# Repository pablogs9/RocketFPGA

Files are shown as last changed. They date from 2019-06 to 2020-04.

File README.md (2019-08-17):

# RocketFPGA :sound::rocket:
Why buy a iCE40UP5k breakout when it is possible to make one?
<p align="center">
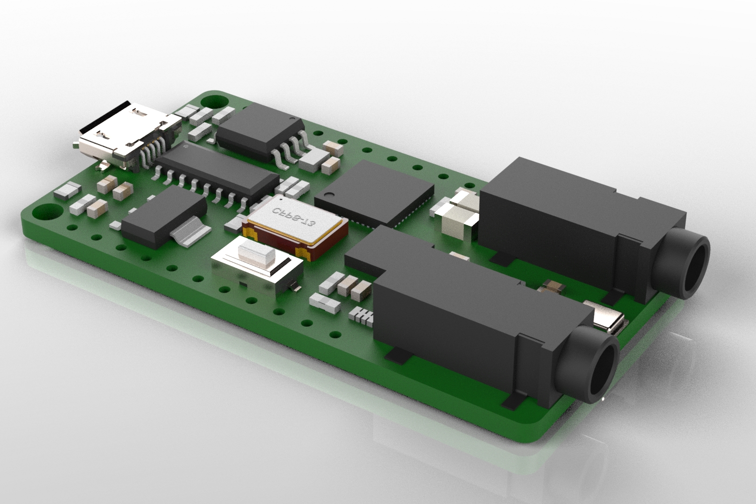
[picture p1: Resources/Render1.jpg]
  
</p>

## What is  this?
This aims to be another FPGA breakout board. What makes this board special is the
usage of a cheap CH551 microcontroller as the bridge between the USB and 
flash memory. This microcontroller could also be used to interface the FPGA and 
the USB, opening a lot of new possibilities.

The current hardware development is focushed on adding an audio codec and a couple
of audio jack to set the focus this board in sound synthesis with 
FPGAs :smiling_imp:.

<p align="center">
  
</p>

## Repo structure:
- Hardware: Contains the Altium PCB design files. (At some point we will clone this on kicad)
- Software
  -  CH551 Bootloader: Contains the source files of the CH551 flash writer.
  -  Code uploader: Contains a python script that uploads the synthesized FPGA code to the board.
  -  FPGA Sample code: Contains a bunch of verilog examples.

## TODO:
- [ ] Improve heavily the documentation (instructions, wiki etc)
- [ ] Finish the board with the audio codec
- [ ] Create audio related verilog code (once the board is finished)
- [ ] Rethink the TODOs

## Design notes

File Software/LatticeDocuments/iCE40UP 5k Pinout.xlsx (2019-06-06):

# Pin Out For iCE5UP5K (iCE40 UltraPlus - 5K)
# Revision 0.4 - Remove FWG49
# Revision 1.1 - Fix RGB pins, swapped C5 & A5 pins as well as 39 & 41
# Updated Jun 19, 2017
FNC | Pin Type | BANK | Differential Pair | UWG30 | SG48
IOB_0a | PIO | 2 |  | E5 | 46
IOB_2a | DPIO | 2 | TRUE_of_IOB_3b | D5 | 47
IOB_3b_G6 | DPIO/GBIN | 2 | COMP_of_IOB_2a | F5 | 44
IOB_4a | DPIO | 2 | TRUE_of_IOB_5b | - | 48
IOB_5b | DPIO | 2 | COMP_of_IOB_4a | - | 45
IOB_6a | PIO | 2 |  | - | 2
IOB_8a | DPIO | 2 | TRUE_of_IOB_9b | - | 4
IOB_9b | DPIO | 2 | COMP_of_IOB_8a | E4 | 3
IOB_10a | DPIO | 1 | TRUE_of_IOB_11b | C3 | -
IOB_11b_G5 | DPIO/GBIN | 1 | COMP_of_IOB_10a | F4 | -
creset_b | CONFIG | 1 |  | F3 | 8
IOB_12a_G4_CDONE | CONFIG/DPIO/GBIN | 1 | TRUE_of_IOB_13b | D3 | -
CDONE | CONFIG | 1 |  | - | 7
IOB_13b | DPIO | 1 | COMP_of_IOB_12a | E3 | 6
IOB_16a | PIO | 1 |  | - | 9
IOB_18a | PIO | 1 |  | - | 10
IOB_20a | PIO | 1 |  | - | 11
IOB_22a | DPIO | 1 | TRUE_of_IOB_23b | - | 12
IOB_23b | DPIO | 1 | COMP_of_IOB_22a | - | 21
IOB_24a | DPIO | 1 | TRUE_of_IOB_25b | B1 | 13
IOB_25b_G3 | DPIO/GBIN | 1 | COMP_of_IOB_24a | F2 | 20
IOB_29b | PIO | 1 |  | - | 19
IOB_31b | PIO | 1 |  | - | 18
IOB_32a_SPI_SO | DPIO/CONFIG_SPI | 1 |  | F1 | 14
IOB_33b_SPI_SI | DPIO/CONFIG_SPI | 1 |  | E1 | 17
IOB_34a_SPI_SCK | DPIO/CONFIG_SPI | 1 |  | D1 | 15
IOB_35b_SPI_SS | DPIO/CONFIG_SPI | 1 |  | C1 | 16
VCCPLL | VCCPLL |  |  | B2 | 29
IOT_36b | DPIO/I3C | 0 | COMP_of_IOT_37a | A1 | 25
IOT_37a | DPIO/I3C | 0 | TRUE_of_IOT_36b | A2 | 23
IOT_38b | DPIO | 0 | COMP_of_IOT_39a | - | 27
IOT_39a | DPIO | 0 | TRUE_of_IOT_38b | - | 26
IOT_41a | PIO | 0 |  | - | 28
IOT_42b | DPIO | 0 | COMP_of_IOT_43a | - | 31
IOT_43a | DPIO | 0 | TRUE_of_IOT_42b | - | 32
IOT_44b | DPIO | 0 | COMP_of_IOT_45a | - | 34
IOT_45a_G1 | DPIO/GBIN | 0 | TRUE_of_IOT_44b | - | 37
IOT_46b_G0 | DPIO/GBIN | 0 |  | B3 | 35
IOT_47a | PIO | 0 |  | A4 | -
IOT_48b | DPIO | 0 | COMP_of_IOT_49a | - | 36
IOT_49a | DPIO | 0 | TRUE_of_IOT_48b | - | 43
IOT_50b | DPIO | 0 | COMP_of_IOT_51a | - | 38
IOT_51a | DPIO | 0 | TRUE_of_IOT_50b | - | 42
RGB2 | LED | 0 |  | C5 | 41
RGB1 | LED | 0 |  | B5 | 40
RGB0 | LED | 0 |  | A5 | 39
GND | GND | GND |  | B4 | Paddle
GND | GND | GND |  | E2 | Paddle
GND | GND | GND |  | - | Paddle
VCC | VCC | VCC |  | C2 | 5
VCC | VCC | VCC |  | - | 30
VCCIO_0 | VCCIO | 0 |  | A3 | 33
SPI_Vccio1 | VCCIO | 1 |  | D2 | 22
VCCIO_2 | VCCIO | 2 |  | C4 | 1
VPP_2V5 | VPP | VPP |  | D4 | 24
*SG48 GND is connected to package paddle

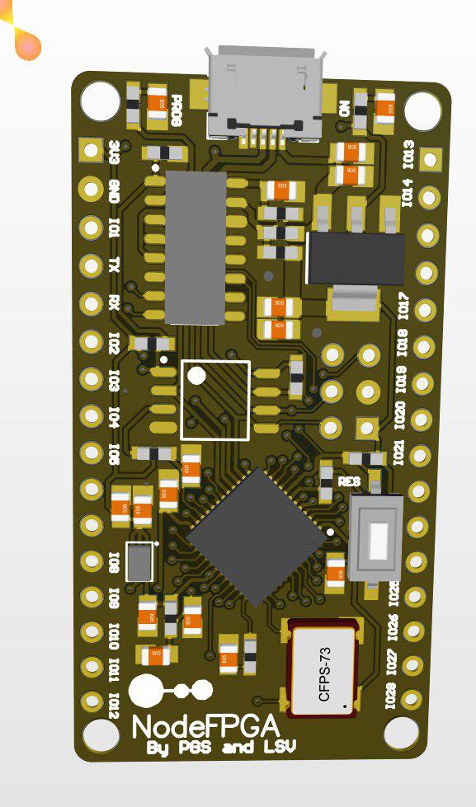
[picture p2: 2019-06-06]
Resources/NodeFPGA_cad.jpg

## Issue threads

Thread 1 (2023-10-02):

Where do I buy one?

PythonLinks, 2023-10-02:
I believe that there are no shipping ICE40 boards with audio ports.   There are some with pmod ports, but then one has to buy more stuff to plug in.  It is an important market which is not being served.

There are several of us interested in Audio.
We are looking at the Pico-Ice
 https://pico-ice.tinyvision.ai/

And the Pico Fabric.
https://picolemon.com/board/picofabric

The problem with the Pico Ice is that we have to separately buy the Diligent pmod, and worse yet solder pmods onto the boards.  Sure I can do that, but my users will have a hard time doing it.  The holes are so small, even I will have a hard time doing it.

The problem with the Pico Fabric is that it does not quite work yet, and they are waiting for parts for 3 more months.  Also it uses the ECP5, and is more expensive.  And it does not have audio input.

You are most welcome to join our discord servers and meet us.

Pico Ice Discord Server:  https://discord.gg/MY6cAgs5

Pico Fabric Discord Server: https://discord.gg/8Kdr2TtY

The great thing about joining this group, is that we will then build the Audio Verilog for you.  In fact I am already building it.  The Upduino has one pmod  presoldered where I can plug in the Diligent stereoaudio pmod. Or at least the audio out part of that Diligent audio pmod.   At least two of us have that UPduino board.

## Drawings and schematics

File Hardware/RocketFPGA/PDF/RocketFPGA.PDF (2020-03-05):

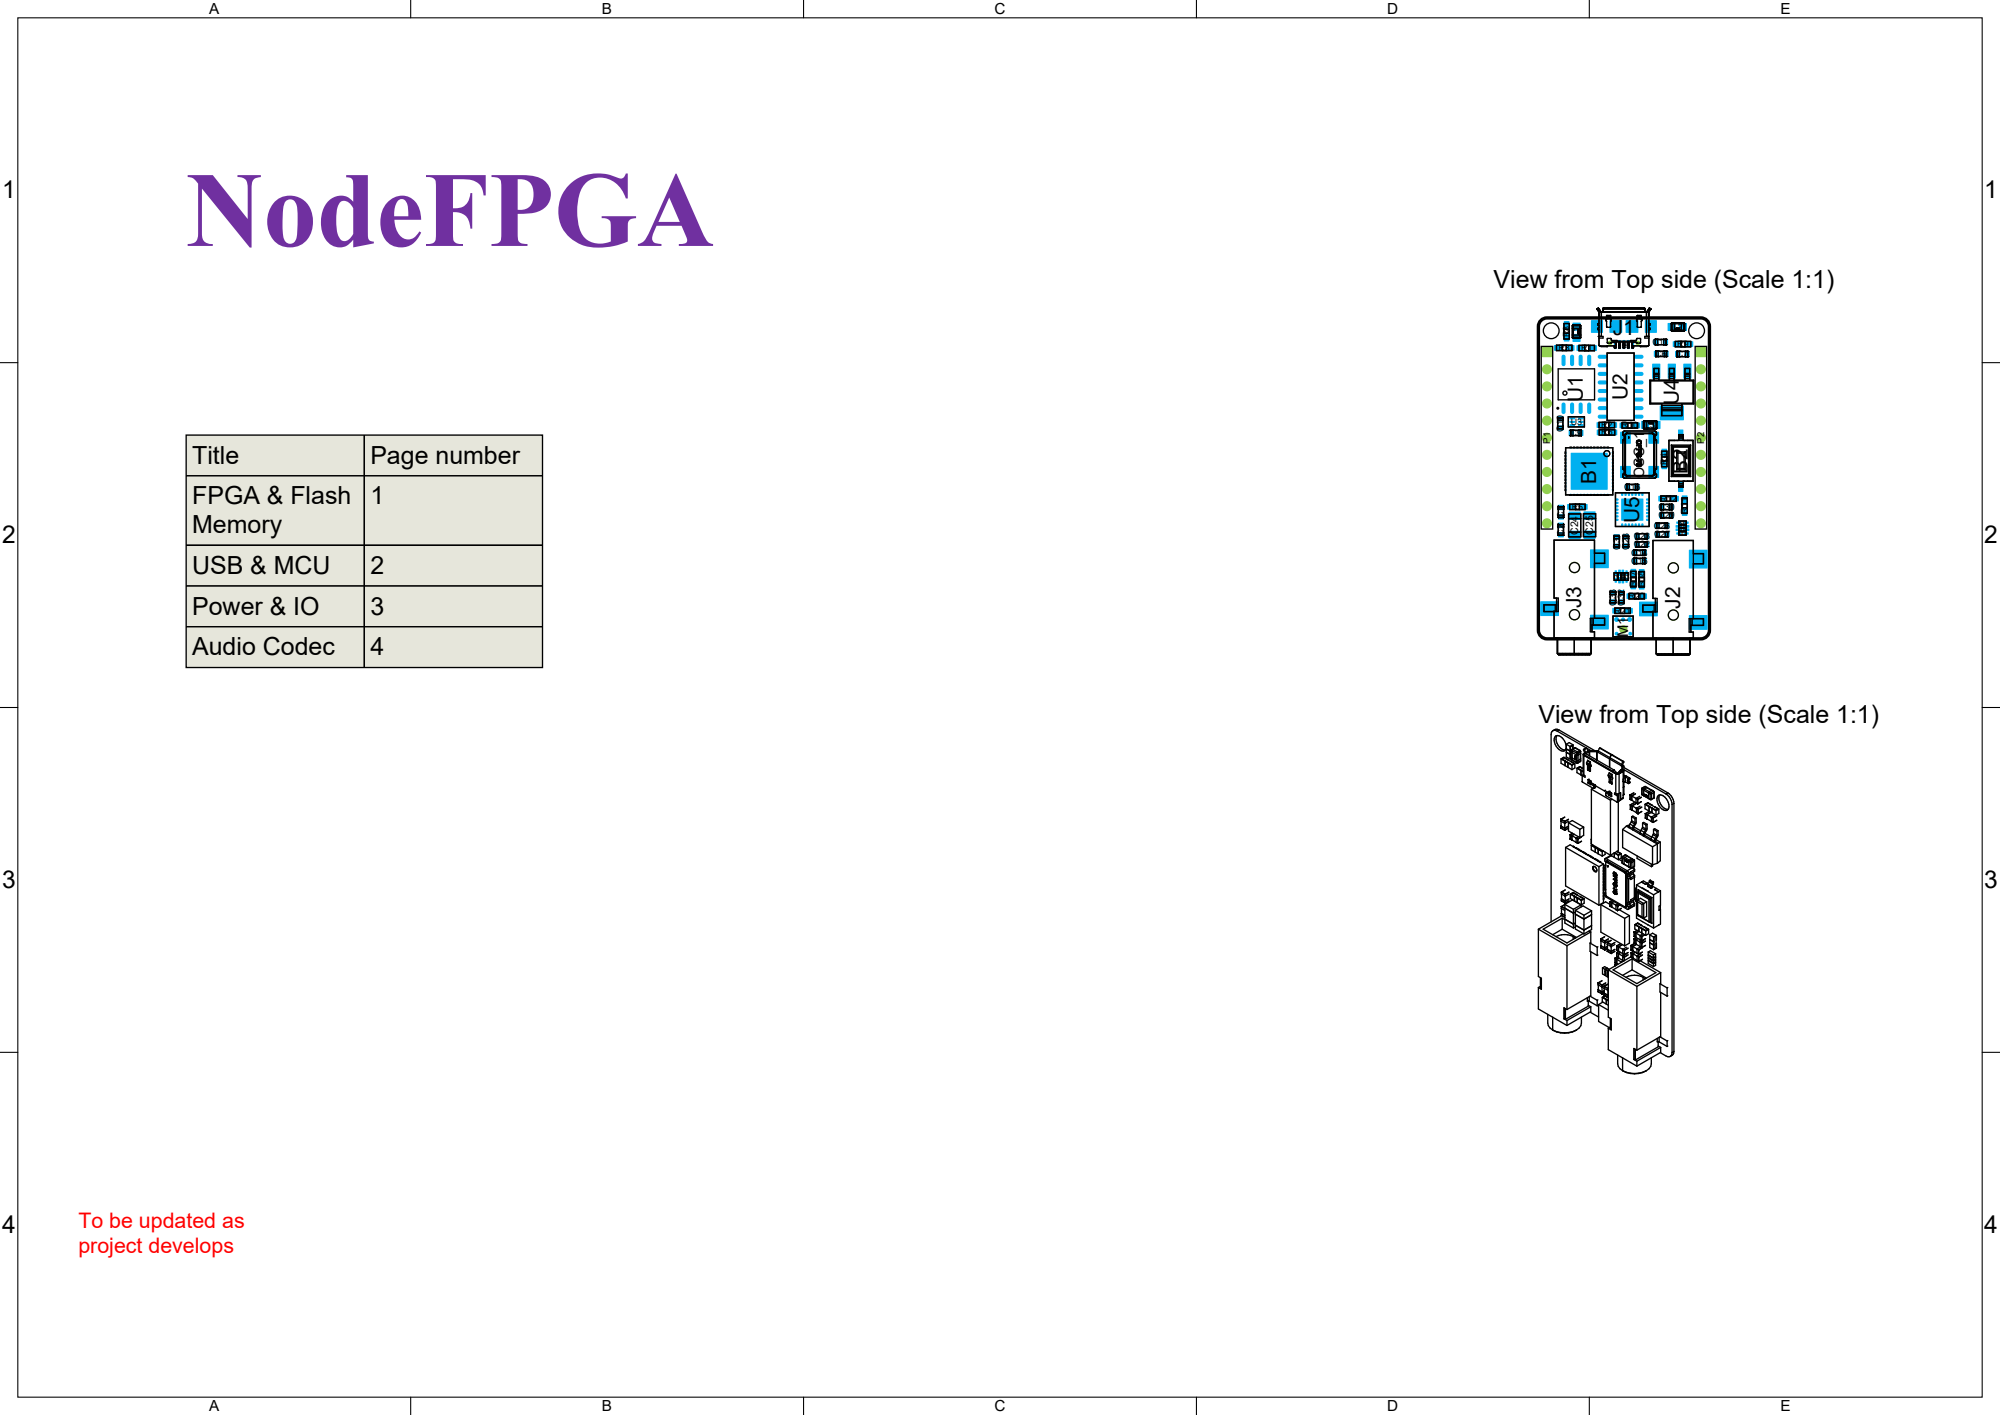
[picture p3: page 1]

View from Top side (Scale 1:1)

To be updated as

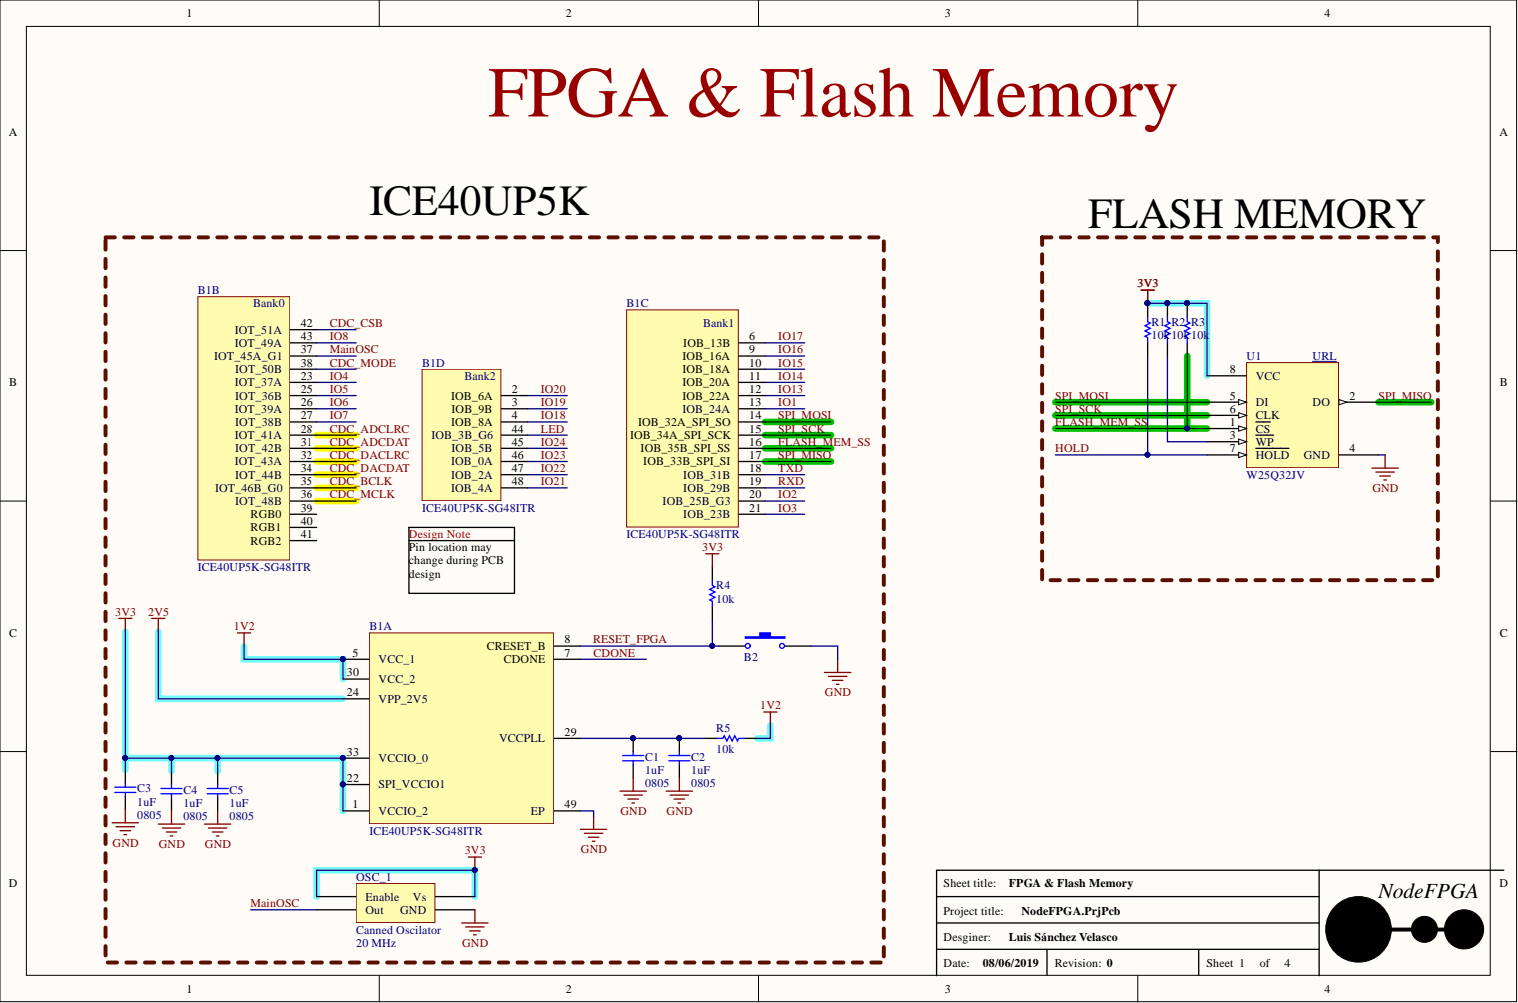
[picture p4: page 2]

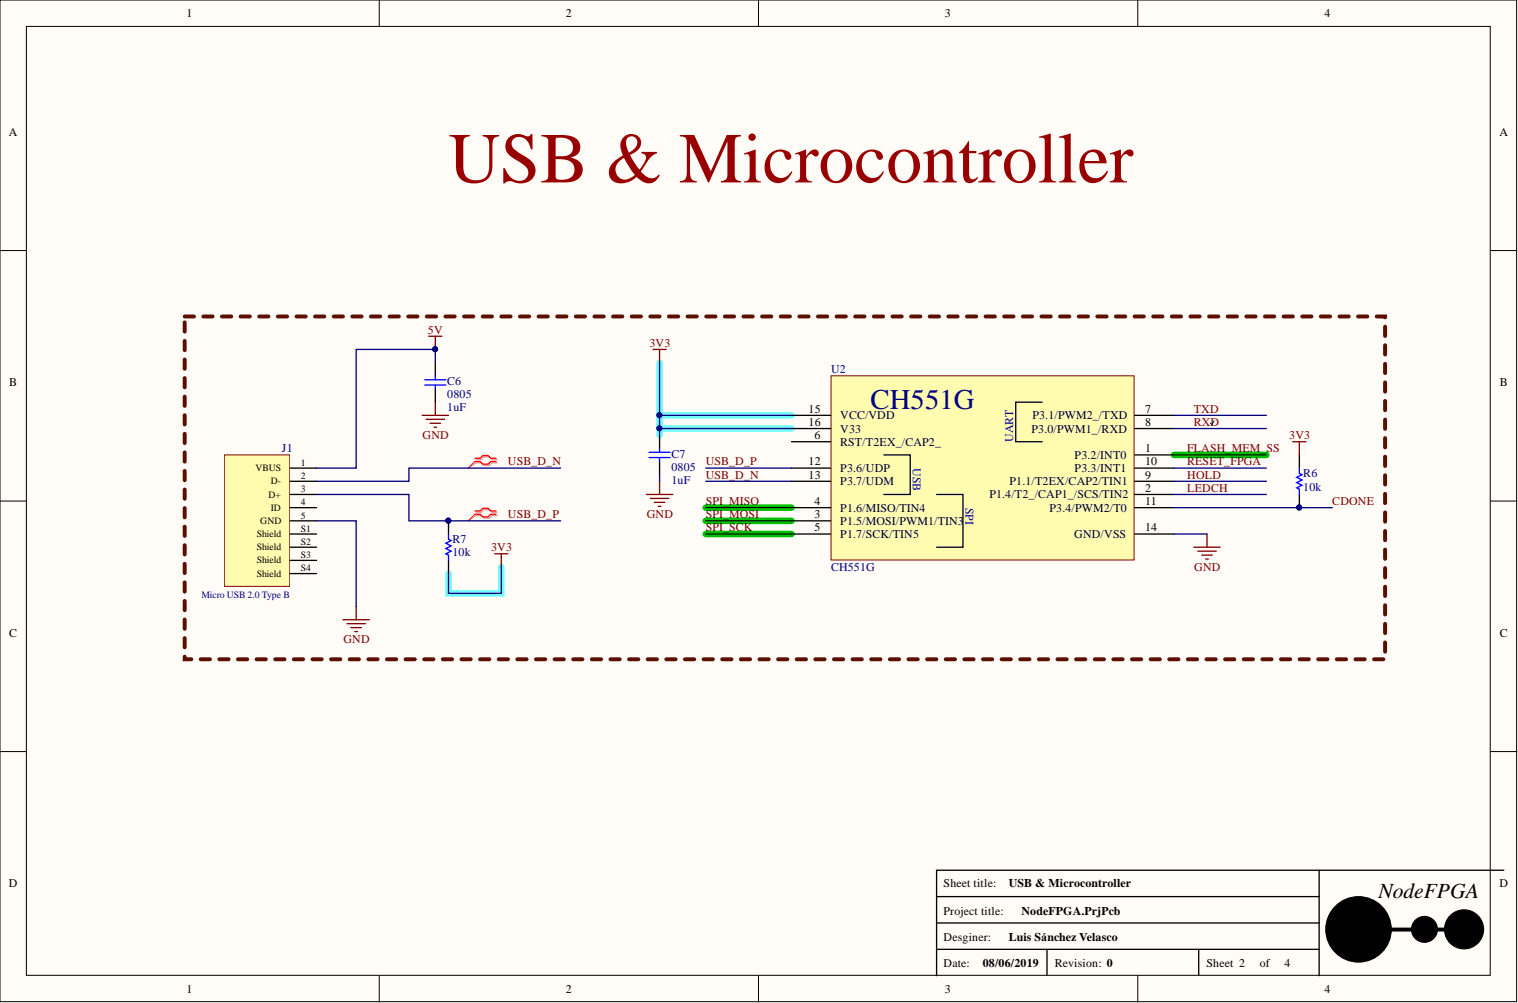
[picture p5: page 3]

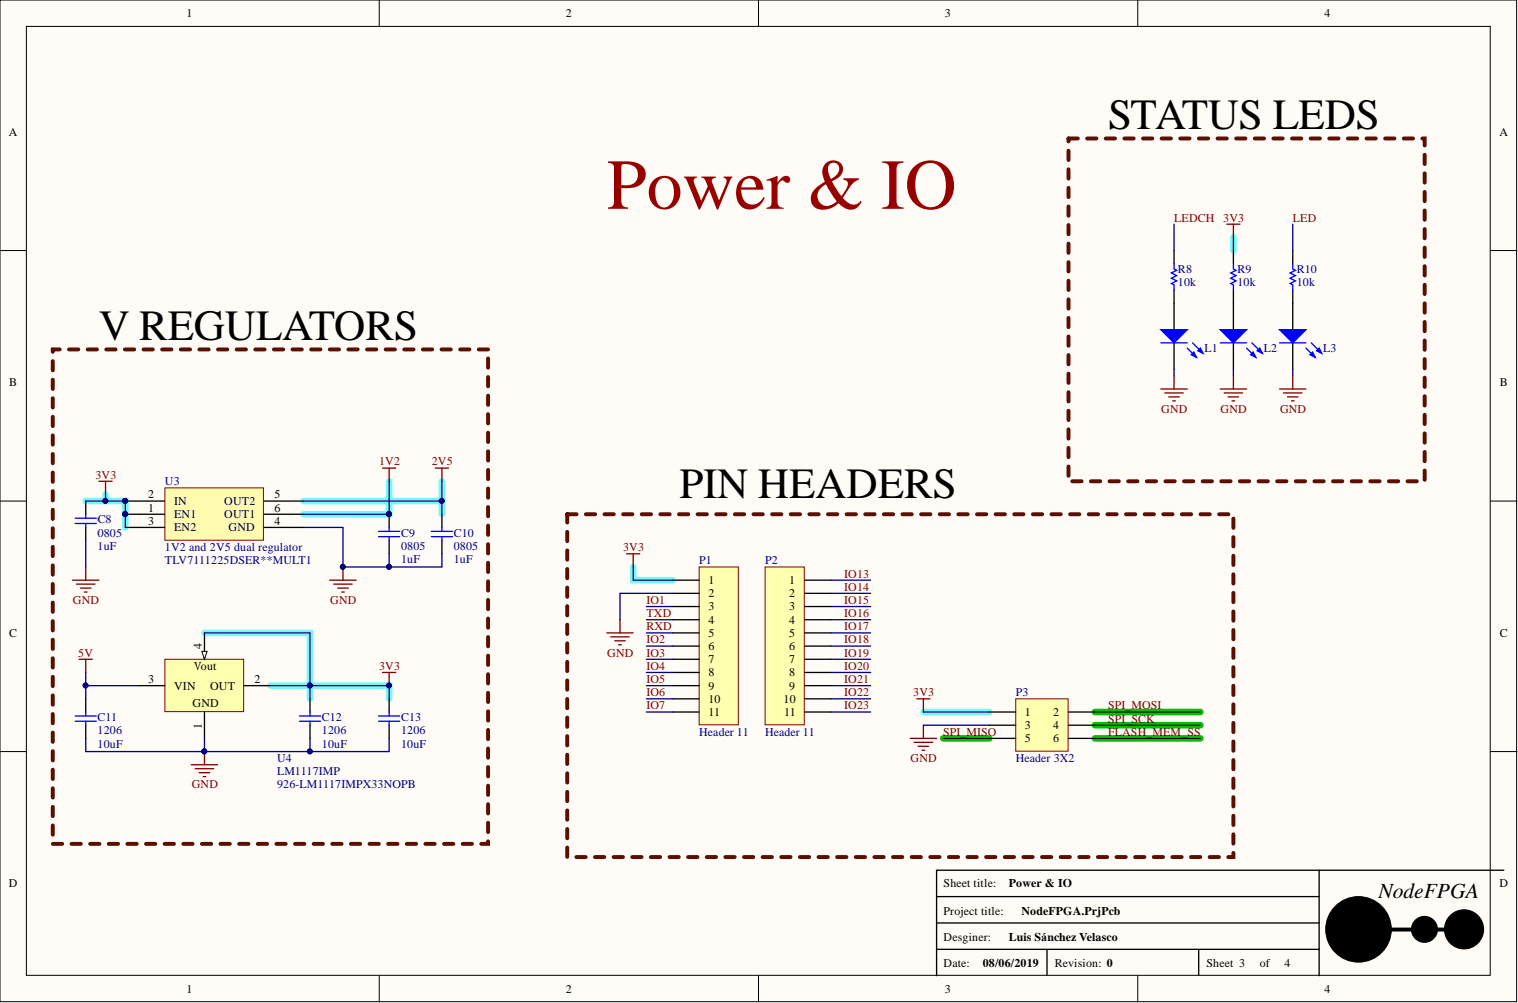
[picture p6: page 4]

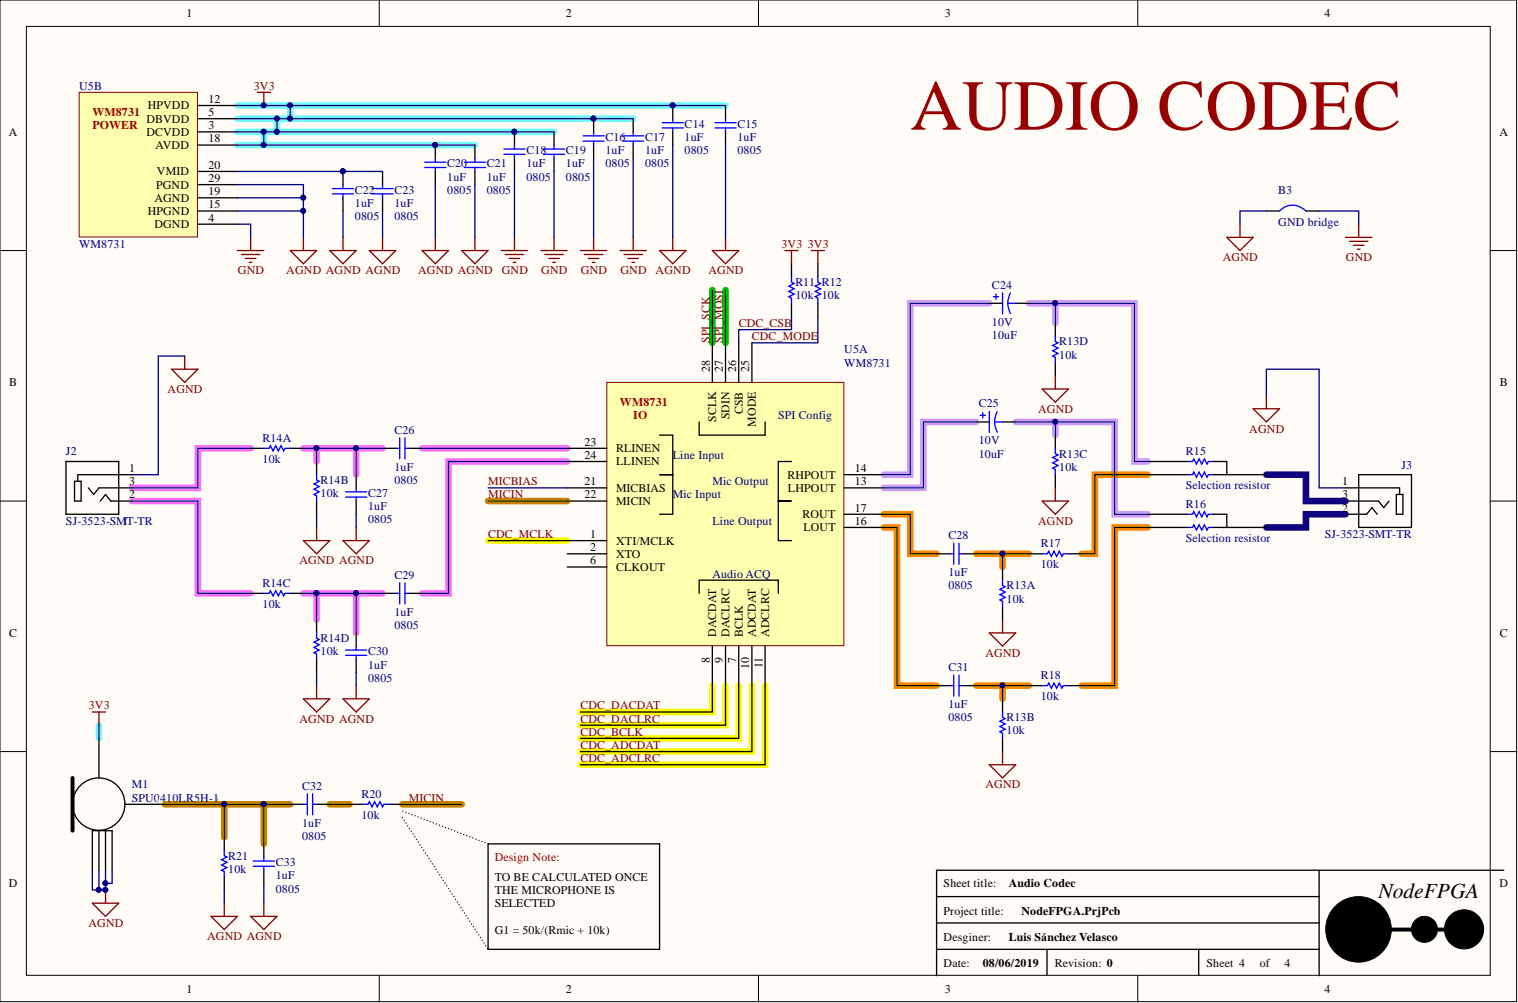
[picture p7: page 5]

MODE 25 CSB 26 SDIN 27 SCLK 28

WM8731 IO RLINEN 23 | SPI Config

MICBIAS | MICBIAS 21

Design Note:
TO BE CALCULATED ONCE
THE MICROPHONE IS
SELECTED

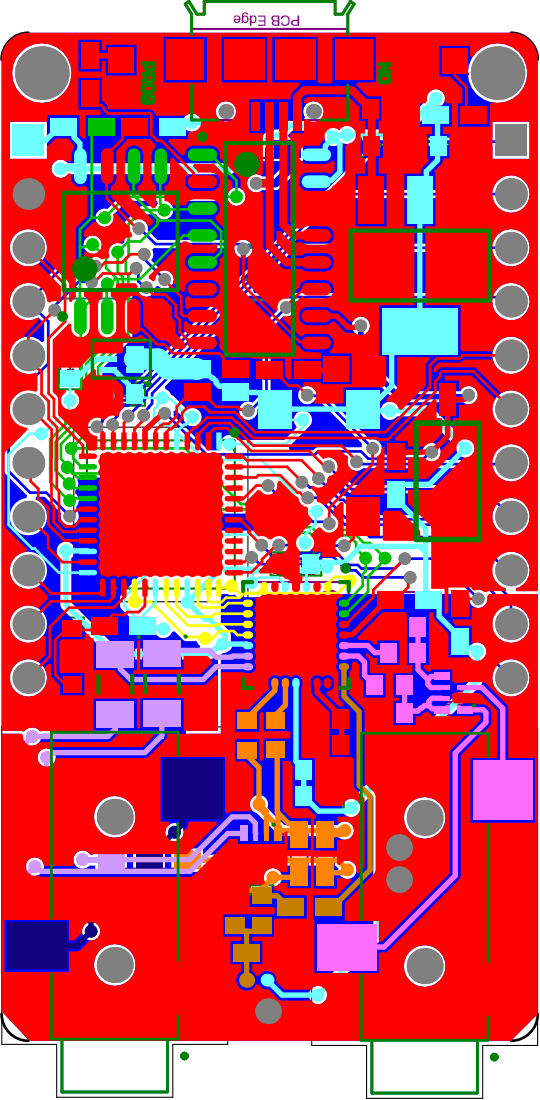
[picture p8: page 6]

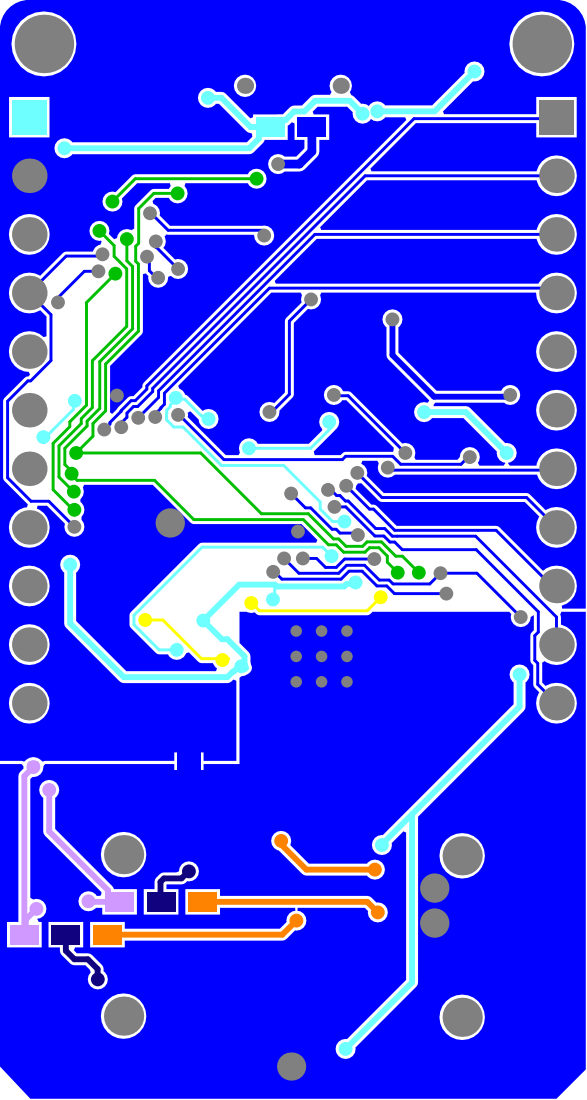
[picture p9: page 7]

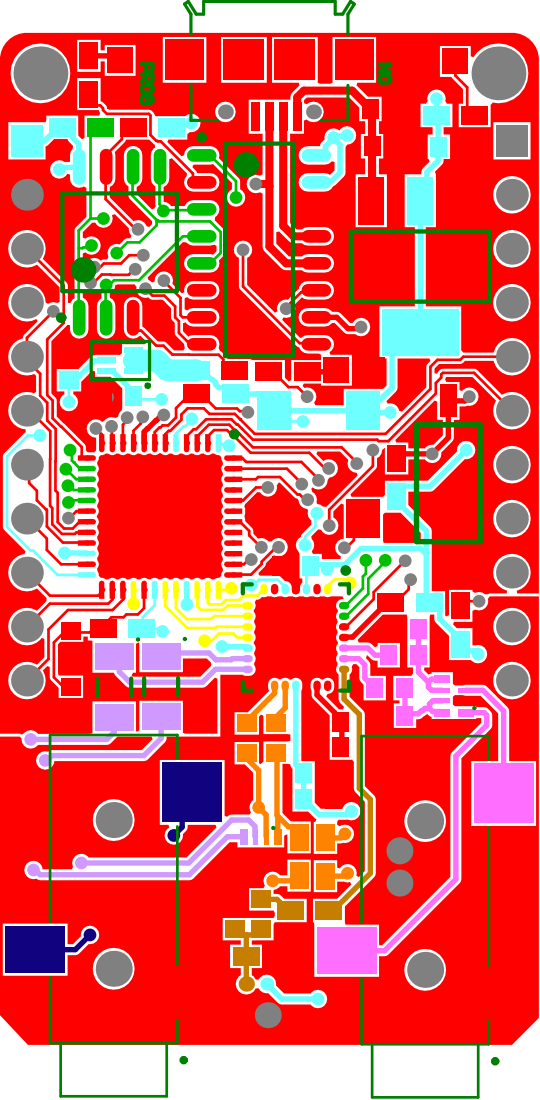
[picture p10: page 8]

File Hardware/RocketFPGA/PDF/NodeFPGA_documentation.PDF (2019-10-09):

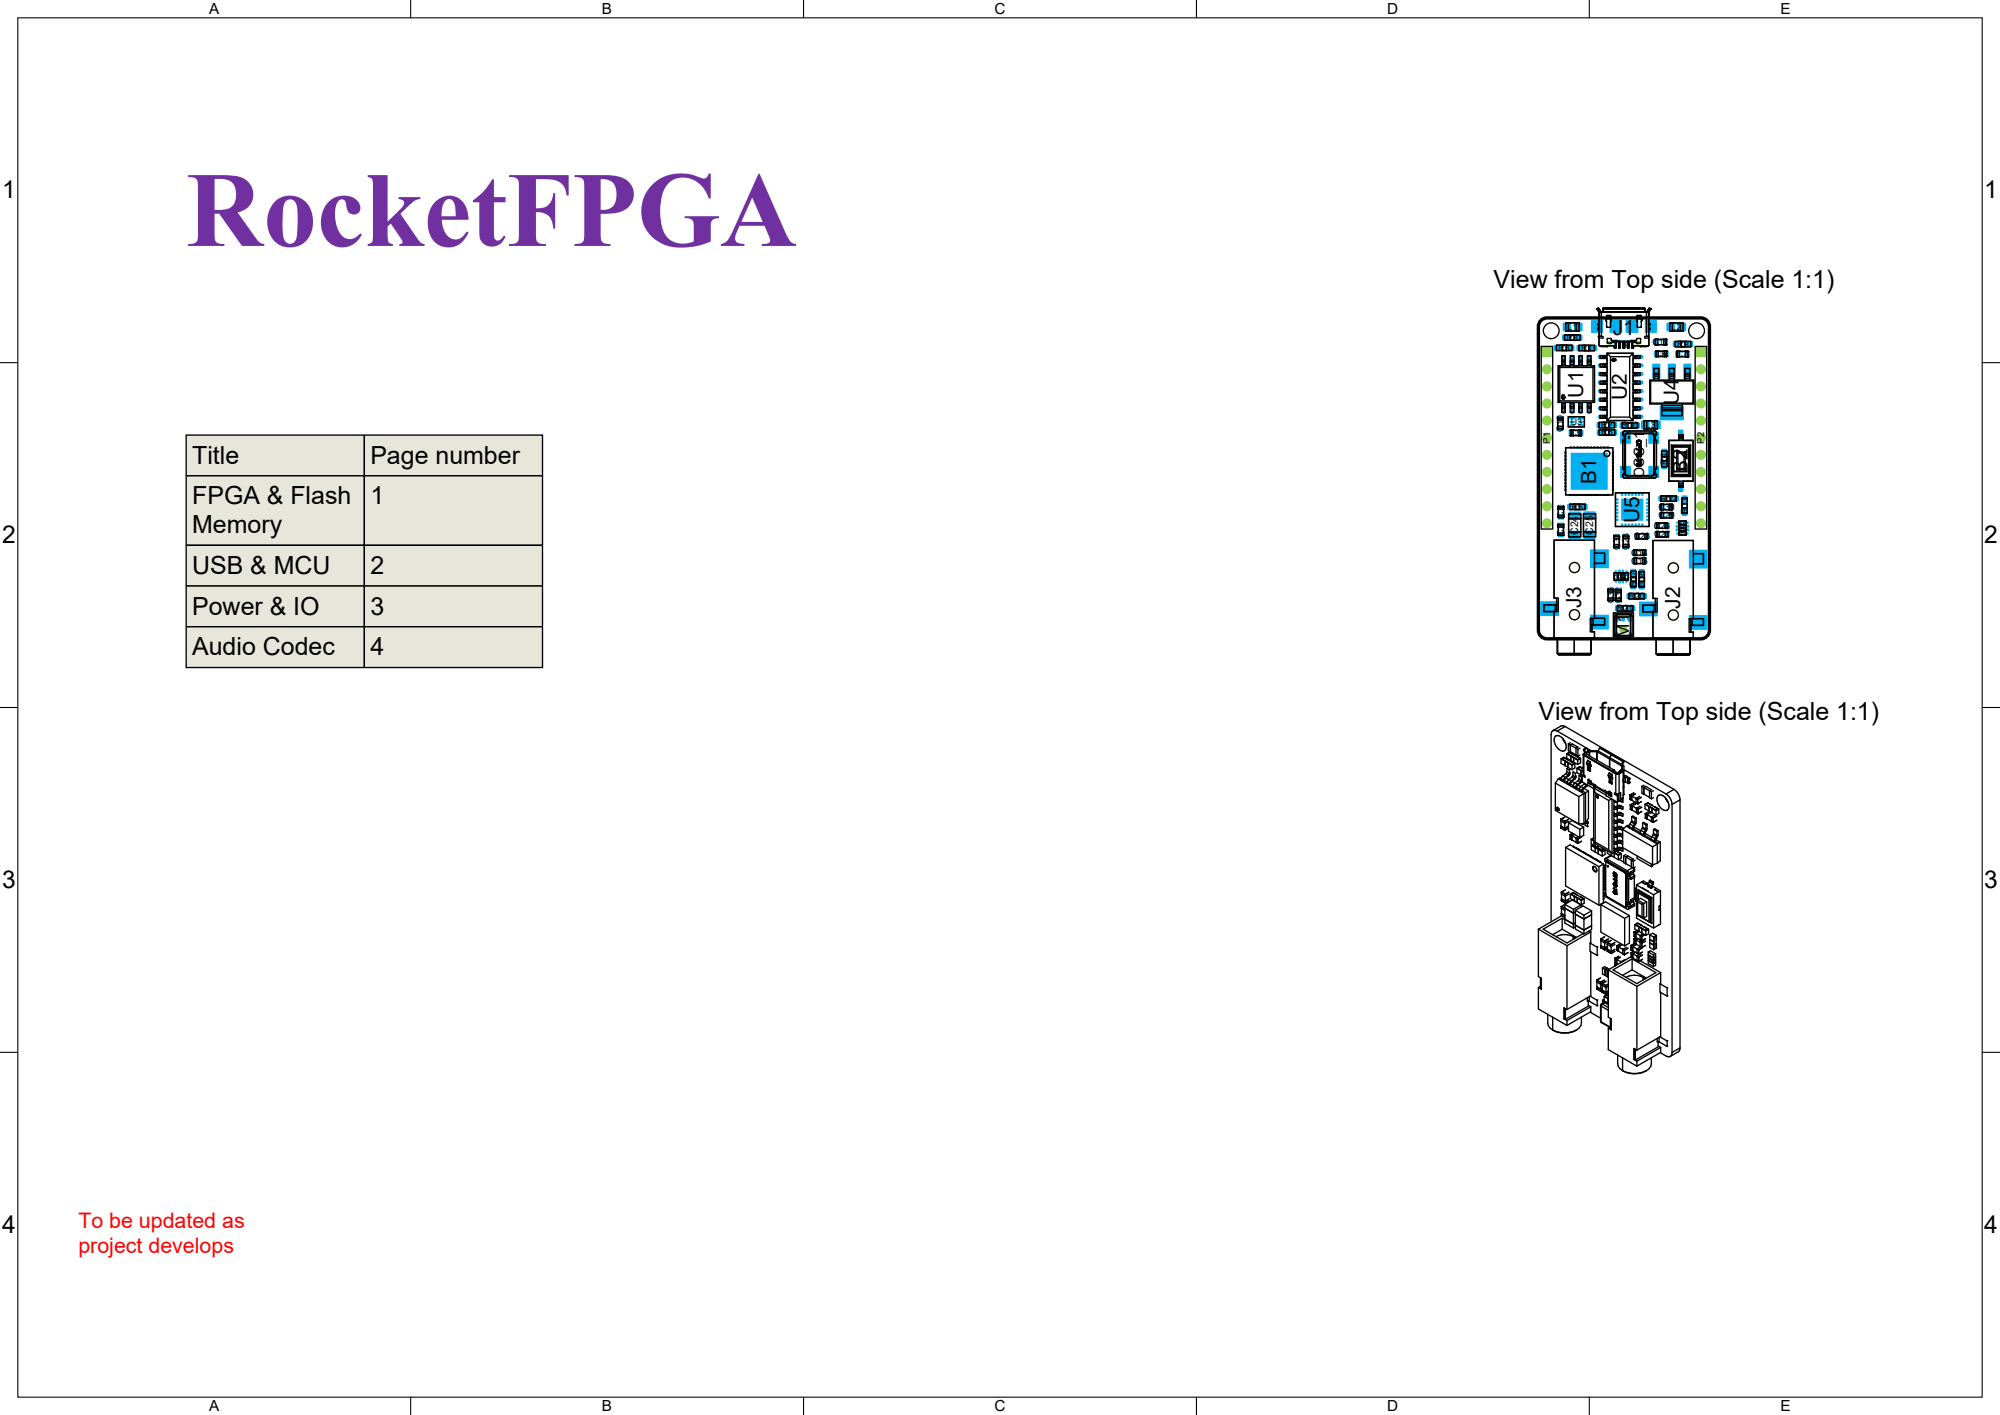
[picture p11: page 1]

View from Top side (Scale 1:1)

To be updated as

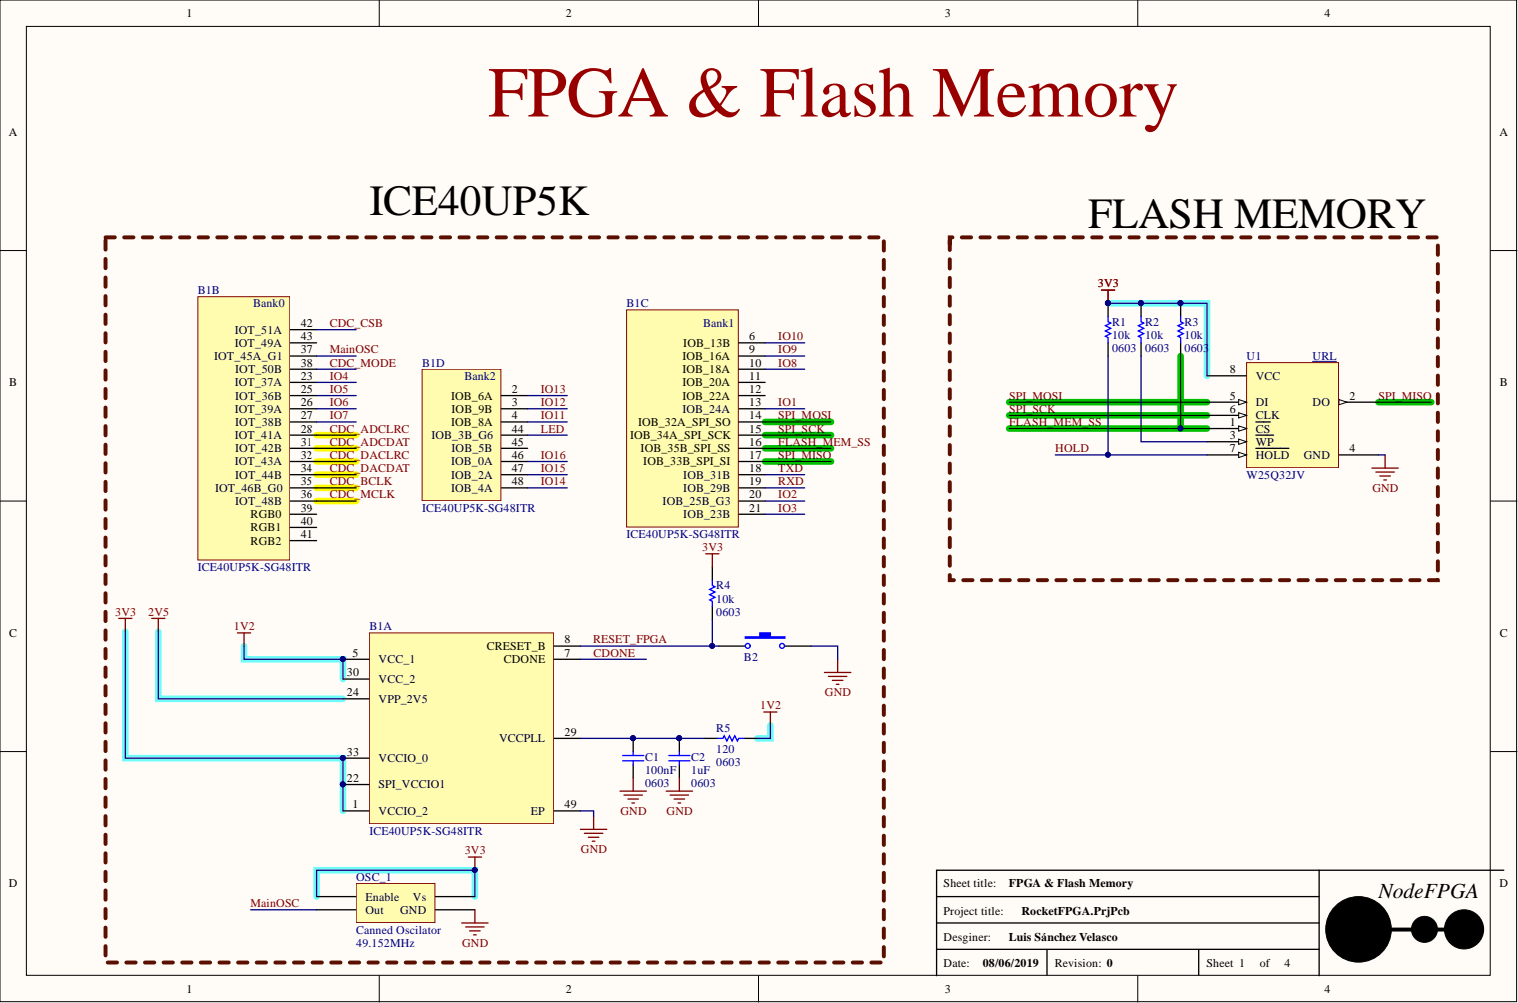
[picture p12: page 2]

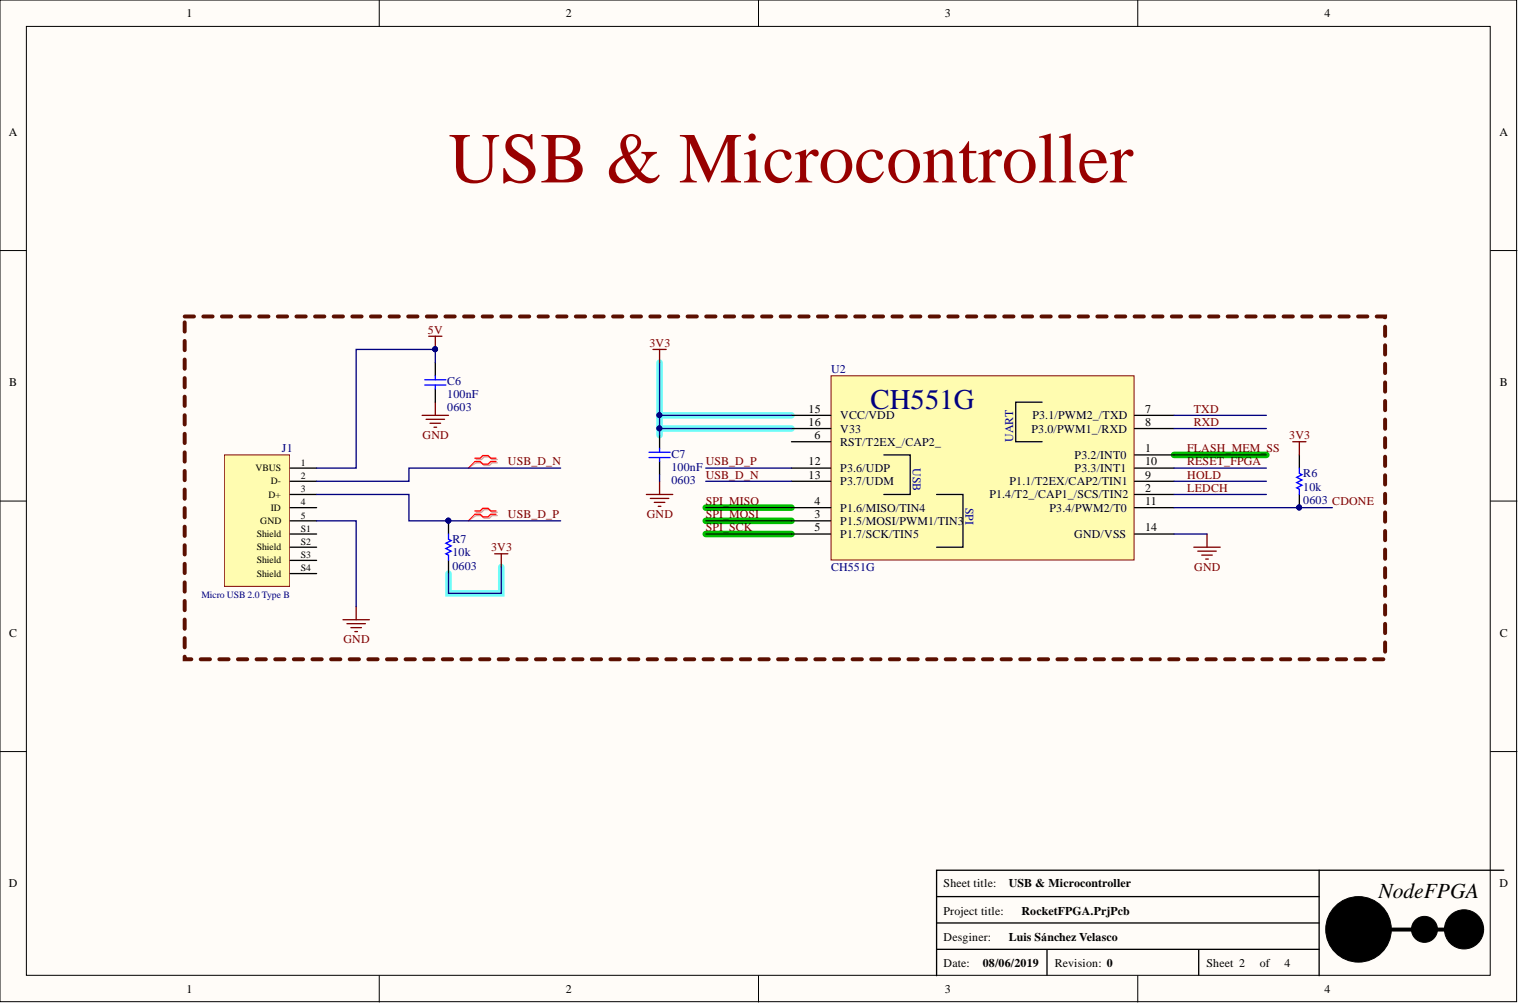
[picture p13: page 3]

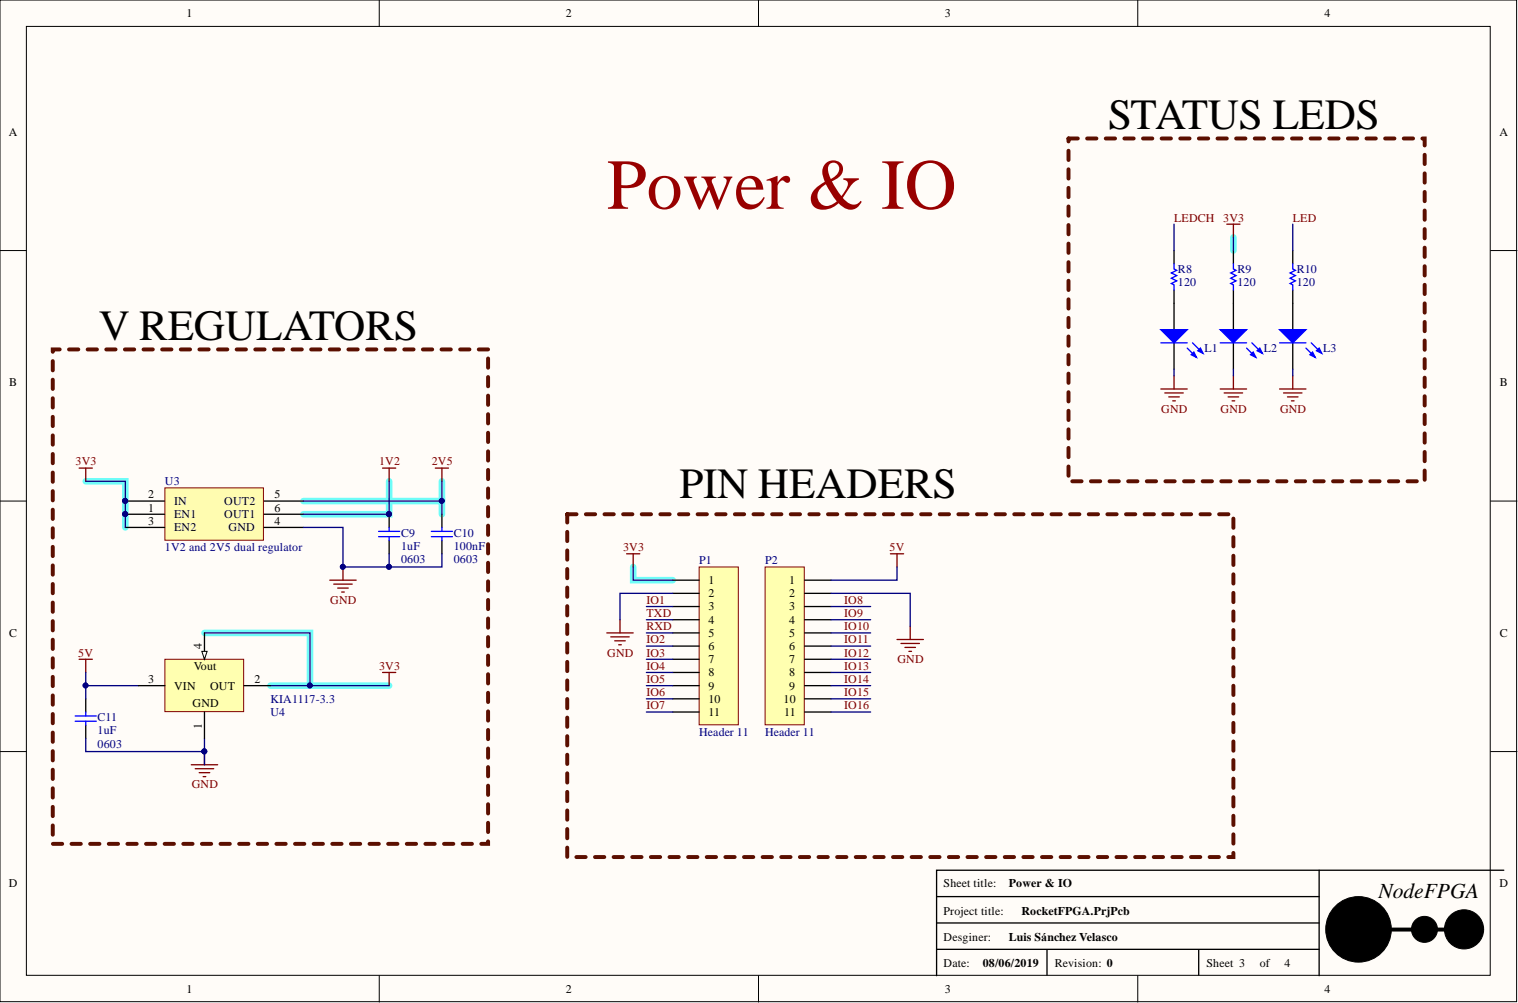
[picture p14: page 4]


MODE 25 CSB 26 SDIN 27 SCLK 28

WM8731 IO RLINEN 23 | SPI Config

MICIN | MICBIAS 21

Design Note:
TO BE CALCULATED ONCE
THE MICROPHONE IS
SELECTED




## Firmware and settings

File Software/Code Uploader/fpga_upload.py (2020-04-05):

#! /usr/bin/env python
import serial
import time
import argparse
import sys

def writeBytes(ser, d):
    ser.write(bytearray([ord('W')]))
    ser.write(len(d).to_bytes(4, byteorder='little'))
    for i,c in enumerate(d):
        ser.write([c])
        if i == 1:
            print("Erasing memory")
        else:
            print("Writing: {:.2f}%".format(100*i/len(d)), end="\r")
        # ack = ser.read()

def readBytes(ser,l):
    ser.write(bytearray([ord('R')]))
    ser.write(l.to_bytes(4, byteorder='little'))
    value = []
    for i in range(l):
        d = ser.read()
        value.append(d)
        print("Reading: {:.2f}%".format(100*i/l),end="\r")

    return value



def start_flash(port, baudrate, file, no_verify):
    try:
        ser = serial.Serial(port,baudrate)
        ser.rts = 1
    except serial.serialutil.SerialException:
        print("The port '{}' could not be oppended at {} bauds".format(port, baudrate))
        exit()
    try:
        f = open(file, "rb")
    except FileNotFoundError:
        print("File {} not found in path".format(file))
        exit()

    txdata = f.read()
    dlen = len(txdata)
    print("Loading File: {:s} -- {:0.2f} KB".format(file,len(txdata)/1024))

    now = time.time()
    writeBytes(ser, txdata)
    print("Writing time {:.2f} s".format(time.time()-now))

    time.sleep(0.1)
    now = time.time()
    if not no_verify:
        data = readBytes(ser,dlen)
        print("Reading time {:.2f} s".format(time.time()-now))
        print("DATA VERIFIED: " + str(all([x == ord(y) for (x,y) in zip(txdata,data)])))
    
    ser.write(bytearray([ord('A')]))
    ser.close() 
    

if __name__ == '__main__':
    parser = argparse.ArgumentParser(description='Flash FPGA board')
    parser.add_argument('-d', '--dev', dest='port', type=str,required=True, 
                        help='Serial port where to write to')
    parser.add_argument('-b', dest='baudrate', type=int,  default=57600,
                        help='Baudrate of the serial port (default 57600)')
    parser.add_argument('-f', dest='file', type=str, required=True,
                        help='bitestream to flash')
    parser.add_argument('--no-verify',  action='store_true',
                    help='Use this flag to skip verification')
    if sys.version_info[0] < 3:
        raise Exception("Must be using Python 3")
    args = parser.parse_args()
    start_flash(args.port, args.baudrate, args.file, args.no_verify)

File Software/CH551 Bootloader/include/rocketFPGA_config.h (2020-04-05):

#include <compiler.h>
#include <ch554.h>

#define RESET_FPGA_PIN 3
#define FLASH_SS_PIN 2
#define LED_PIN 4
#define FLASH_DO_PIN 5
#define FLASH_DI_PIN 6
#define FLASH_CK_PIN 7

#define ENABLE_BIT(R,B) R = R |	(1<<B)
#define DISABLE_BIT(R,B) R = R & ~(1<<B)

SBIT(FLASH_DO, 0x90, FLASH_DO_PIN);
SBIT(FLASH_DI, 0x90, FLASH_DI_PIN);
SBIT(FLASH_CK, 0x90, FLASH_CK_PIN);

SBIT(FLASH_SS, 0xB0, FLASH_SS_PIN);
SBIT(RESET_FPGA, 0xB0, RESET_FPGA_PIN);
SBIT(LED, 0x90, LED_PIN);

void enableFlashSS();
void enableFPGAReset();
void disableFlashSS();
void disableFPGAReset();
void triestateFlashSS();
void triestateFPGAReset();
void enablePreFlash();
void disablePreFlash();
void enableLED();
void disableLED();

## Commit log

2019-06-06 improved schematics
    [01_FPGA_FlashMem.SchDoc, 02_USB_MCU.SchDoc, 03_Power_IO.SchDoc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]
2019-06-06 start of codec sch
    [04_AudioCodec.SchDoc]
2019-06-08 Sch with audio codec rev 0
    [01_FPGA_FlashMem.SchDoc, 02_USB_MCU.SchDoc, 03_Power_IO.SchDoc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]
2019-06-08 added templates
    [01_FPGA_FlashMem.SchDoc, 02_USB_MCU.SchDoc, 03_Power_IO.SchDoc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]
2019-06-08 added cover schematic page
2019-06-08 added documentation PDF and output job
    [NodeFPGA.PrjPcb]
2019-06-08 fixed output selecion resistor mistake
    [04_AudioCodec.SchDoc]
2019-06-08 SPI pins renaming
    [01_FPGA_FlashMem.SchDoc, 02_USB_MCU.SchDoc, 03_Power_IO.SchDoc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]
2019-06-08 added microphone input stage
    [04_AudioCodec.SchDoc, NodeFPGA.PrjPcb]
2019-06-08 updated schematics PDF with last 2 commits
2019-06-09 fixed FPGA SPI pin asignation
    [01_FPGA_FlashMem.SchDoc]
2019-06-09 change resistors to resistor arrays
    [01_FPGA_FlashMem.SchDoc, 02_USB_MCU.SchDoc, 03_Power_IO.SchDoc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]
2019-06-09 added bridge to pcb lib
2019-06-10 updated PCB lbs
    [NodeFPGA.PrjPcb]
2019-06-11 updated SCH from libs
    [03_Power_IO.SchDoc, 04_AudioCodec.SchDoc, NodeFPGA.PrjPcb]
2019-06-11 placing, decouplngs caps wont fit
    [01_FPGA_FlashMem.SchDoc, 02_USB_MCU.SchDoc, 03_Power_IO.SchDoc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]
2019-06-12 change caps to 0603 package
    [01_FPGA_FlashMem.SchDoc, 02_USB_MCU.SchDoc, 03_Power_IO.SchDoc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]
2019-06-12 changed hp cap to tantalum
    [04_AudioCodec.SchDoc, NodeFPGA.PcbDoc]
2019-06-12 added mems microphone
    [04_AudioCodec.SchDoc, NodeFPGA.PcbDoc]
2019-06-12 small replacing
    [NodeFPGA.PcbDoc]
2019-06-13 audio and spi routed
    [01_FPGA_FlashMem.SchDoc, 04_AudioCodec.SchDoc, NodeFPGA.PcbDoc]
2019-06-13 routing done
    [NodeFPGA.PcbDoc, panel.PcbDoc]
2019-06-14 fixed weird error with FPGA footprint
    [NodeFPGA.PcbDoc, NodeFPGA.PrjPcb]
2019-06-14 repouring polygons
    [NodeFPGA.PcbDoc]
2019-06-14 added net colors
    [01_FPGA_FlashMem.SchDoc, 03_Power_IO.SchDoc, 04_AudioCodec.SchDoc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]
2019-06-14 hotfix on the flash memory foortprint
    [01_FPGA_FlashMem.SchDoc, NodeFPGA.PcbDoc]
2019-06-15 added 5V output pin
    [03_Power_IO.SchDoc, NodeFPGA.PcbDoc, NodeFPGA.PrjPcb]
2019-06-15 remove unused components from schematics
    [01_FPGA_FlashMem.SchDoc, 03_Power_IO.SchDoc, 04_AudioCodec.SchDoc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]
2019-06-15 updated design rules
    [NodeFPGA.PcbDoc, NodeFPGA.PrjPcb]
2019-06-15 straightening tracks
    [NodeFPGA.PcbDoc]
2019-06-15 renamed IO pins
    [01_FPGA_FlashMem.SchDoc, 03_Power_IO.SchDoc, NodeFPGA.PcbDoc]
2019-06-15 added silks
    [NodeFPGA.PcbDoc]
2019-06-15 tented all vias
    [NodeFPGA.PcbDoc]
2019-06-15 improved pcb lib. Same layer usage for all components
    [NodeFPGA.PcbDoc]
2019-06-15 schematic parameter cleanup
    [01_FPGA_FlashMem.SchDoc, 02_USB_MCU.SchDoc, 03_Power_IO.SchDoc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]
2019-06-17 order by value in BOM
2019-06-22 added vendor for quick BOM
    [01_FPGA_FlashMem.SchDoc, 02_USB_MCU.SchDoc, 03_Power_IO.SchDoc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]
2019-08-17 Update 3D models
    [04_AudioCodec.SchDoc, NodeFPGA.PcbDoc, NodeFPGA.PrjPcb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]
2020-03-16 Intermediate stage
2020-03-22 Echo initial
    Working state
    Working state
    Update
    Refactor pfc
    Filters
    Echo tunned
    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
    [iCE40UP 5k Pinout.xlsx]
2020-03-23 Added slow ADC
2020-04-03 Rename PWM
2020-04-05 Added uart controller
